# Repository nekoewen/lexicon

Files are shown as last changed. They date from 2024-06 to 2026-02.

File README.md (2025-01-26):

# Lexicon 65% Writing Keyboard

The Lexicon (or if you prefer the Lexicon 69 or the Cluney №3) is a 65% keyboard designed for writing prose, available from [WeirdLittleKeebs](https://www.weirdlittlekeebs.com/). With an extensive collection of shortcuts for words, formatting commands, and extended punctuation, this keyboard changes the experience of writing while maintaining a standard QWERTY layout. Check out the User's Guide to see how its unique features work.

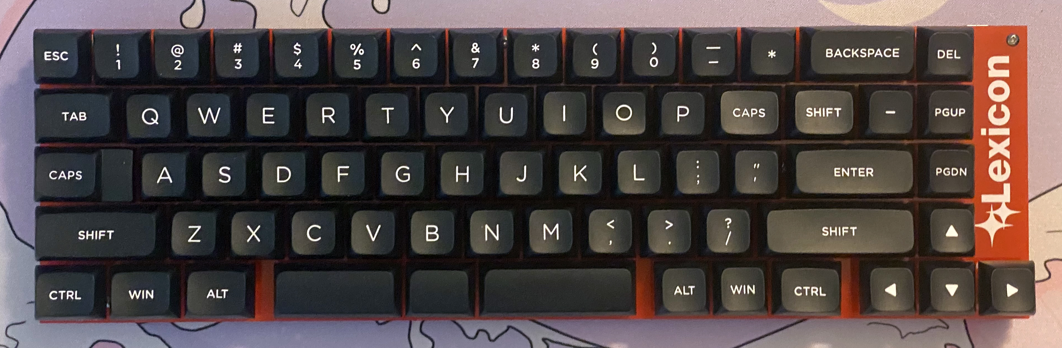
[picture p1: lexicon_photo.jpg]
A photo of a completed Lexicon keyboard


## [Build Guide](https://github.com/nekoewen/lexicon/blob/main/Lexicon%20Build%20Guide.pdf)
If you purchased a set of Lexicon PCB and plates, this guide will walk you through the assembly process.

## [User's Guide](https://github.com/nekoewen/lexicon/blob/main/Lexicon%20User's%20Guide.pdf)
Once you have a Lexicon ready to use, this guide explains all of its features in detail.



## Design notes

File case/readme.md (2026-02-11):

#Lexicon Case

This is a 3D-printable case designed by my good friend [Yenway](https://bsky.app/profile/did:plc:wb7yazpx56bxjeegsce3ni7f). It's made to be printed in two halves that can friction fit together with a pair of printed bars. Those and attaching the PCB make it feel fairly solid. It replaces the keyboard's bottom plate, and has divots for attaching eight adhesive rubber feet.

With PLA I've been able to print these without needing any supports, but it may become necessary for PETG. I recommend using variable layer height to reduce layer lines on the top.

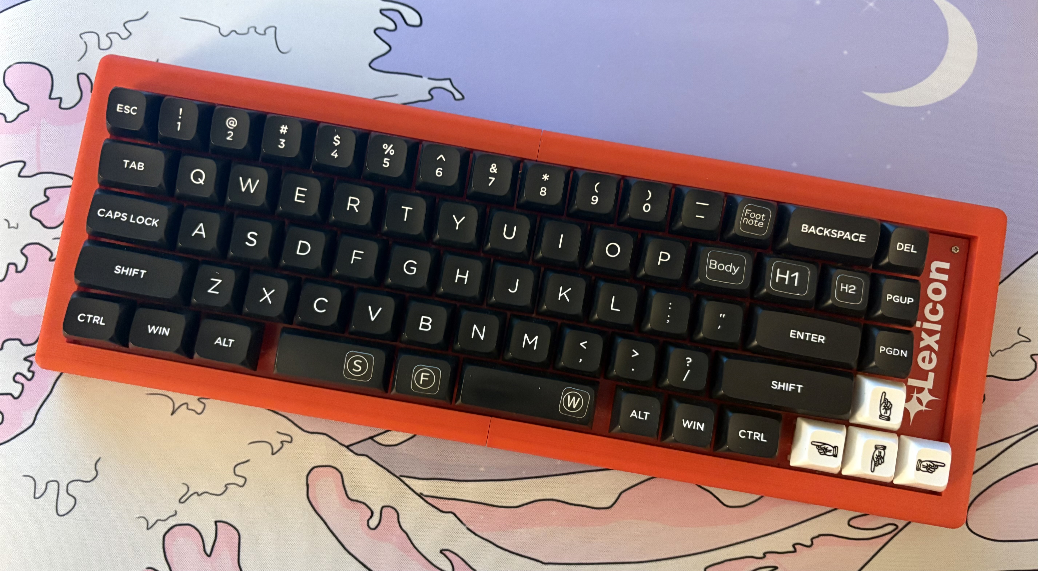
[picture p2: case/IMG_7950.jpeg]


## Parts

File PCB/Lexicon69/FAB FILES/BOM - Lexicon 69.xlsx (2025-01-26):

Designator | Comment | Footprint | LCSC Part #
C80, C81 | 22pF | 402 | C1563
C82 | 47uF | 3216 | C131173
C83, C84, C97 | 10uF | 805 | C15850
C85, C86 | 1uF | 402 | C52923
C87, C88, C90, C91, C92, C93, C94, C95, C96 | 0.1uF | 402 | C1525
C89 | 100nF | 402 | C1525
D1, D2, D3, D4, D5, D6, D7, D10, D11, D12, D14, D15, D16, D17, D18, D19, D20, D21, D22, D23, D24, D25, D26, D27, D28, D29, D30, D31, D32, D33, D34, D35, D36, D37, D38, D39, D40, D41, D42, D43, D45, D46, D47, D48, D49, D50, D51, D52, D53, D54, D55, D56, D57, D58, D60, D61, D62, D63, D64, D65, D66, D70, D72, D73, D74, D77, D132, D133, D134 | D | SOD-123 | C81598
F1 | 1A | 805 | C883105
J2 | USB C | SMD | C165948
R1, R2 | 5.1k | 402
R10, R11 | 22R | 402
R12, R13 | 1k | 402
R14 | 100k | 402
SW65 | RESET | Button_Switch_SMD:SW_SPST_SKQG_WithStem | C318884
U2 | USBLC6-2SC6 | SOT-23-6 | C7519
U4 | AMS1117-3.3 | SOT-223-3 | C6186
U5 | RP2040 | LQFN-56(7x7) | C2040
U6 | W25Q128JVS | SOIC-8-208mil | C97521
Y2 | 12MHz | SMD3225-4P | C9002

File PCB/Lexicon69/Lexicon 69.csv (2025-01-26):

Ref | Qnty | Value | Footprint | Vendor | DNP
C80, C81 | 2 | 22pF | 402 | 402
C82 | 1 | 47uF | 3216 | C131173
C83, C84, C97 | 3 | 10uF | 805 | C15850
C85, C86 | 2 | 1uF | 402 | C52923
C87, C88, C90, C91, C92, C93, C94, C95, C96 | 9 | 0.1uF | 402
C89 | 1 | 100nF | 402 | C1525
D1, D2, D3, D4, D5, D6, D7, D10, D11, D12, D14, D15, D16, D17, D18, D19, D20, D21, D22, D23, D24, D25, D26, D27, D28, D29, D30, D31, D32, D33, D34, D35, D36, D37, D38, D39, D40, D41, D42, D43, D45, D46, D47, D48, D49, D50, D51, D52, D53, D54, D55, D56, D57, D58, D60, D61, D62, D63, D64, D65, D66, D70, D72, D73, D74, D77, D132, D133, D134 | 69 | D | SOD-123 | C81598
F1 | 1 | 1A | 805 | C883105
J2 | 1 | USB C | SMD | C165948
R1, R2 | 2 | 5.1k | 402
R7 | 1 | DNP | 402
R10, R11 | 2 | 22R | 402
R12, R13 | 2 | 1k | 402
R14 | 1 | 100k | 402
SW65 | 1 | RESET | Button_Switch_SMD:SW_SPST_SKQG_WithStem | C318884
U2 | 1 | USBLC6-2SC6 | SOT-23-6 | C7519
U4 | 1 | AMS1117-3.3 | SOT-223-3 | C6186
U5 | 1 | RP2040 | LQFN-56(7x7) | C2040
U6 | 1 | W25Q128JVS | SOIC-8-208mil | C97521
Y2 | 1 | 12MHz | SMD3225-4P | C9002

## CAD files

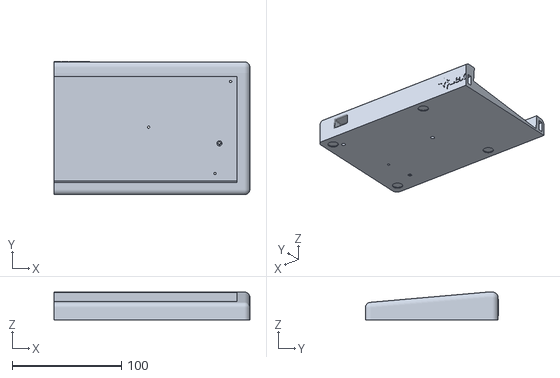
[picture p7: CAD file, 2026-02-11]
case/case_right.stl
179.5 x 122.0 x 25.5

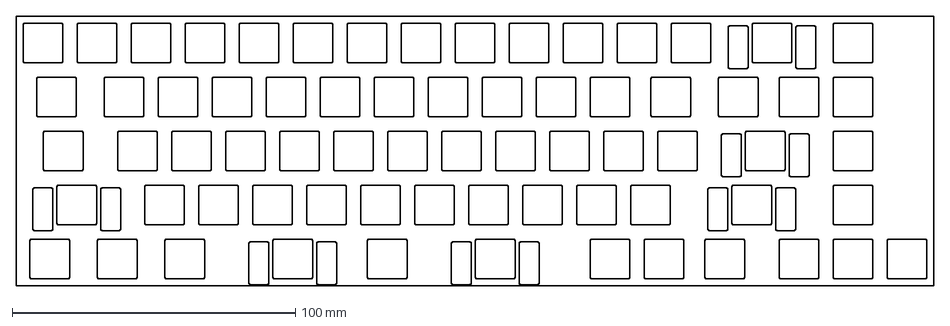
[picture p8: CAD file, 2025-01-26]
PCB/Lexicon69/`DATA/plate.dxf
323.9 x 95.2 mm

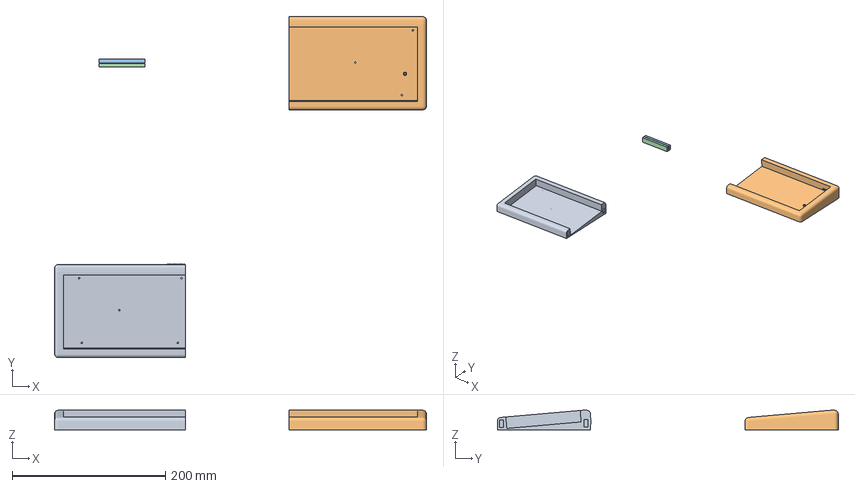
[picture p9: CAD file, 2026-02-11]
case/Lexiboard 2piece v7.3mf
484.8 x 445.0 x 25.5 mm
Body Left
Body Right

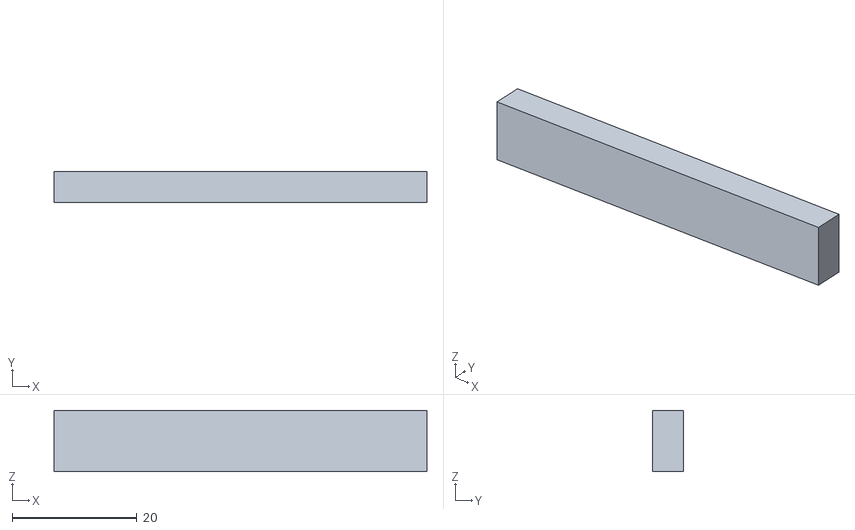
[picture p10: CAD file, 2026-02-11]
case/bar.stl
59.9 x 4.90 x 9.80

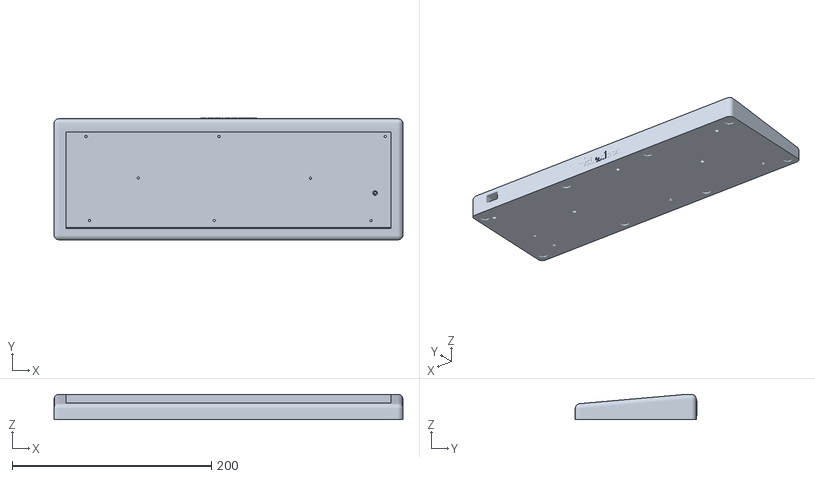
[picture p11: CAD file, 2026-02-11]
case/Lexiboard 1piece.stl
350.1 x 122.0 x 25.5

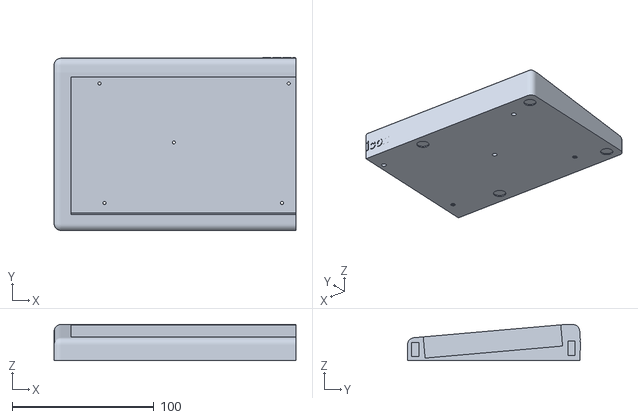
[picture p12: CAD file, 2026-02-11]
case/case_left.stl
170.6 x 122.0 x 25.5

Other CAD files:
case/Lexiboard 1piece v2.3mf

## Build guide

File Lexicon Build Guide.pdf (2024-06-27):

# Lexicon Build Guide

©2024 by Ewen Cluney
Although it has some complex firmware features, the Lexicon’s hardware is standard for hobbyist mechanical keyboards, and not difficult to assemble. This guide will walk you through the necessary steps. Please take appropriate safety precautions when soldering and working on electronics.
Most standard MX keycap sets will work with the Lexicon, but you will need 1.25u, 2.25u, and 2.75u keycaps for the split spacebar. Many keycap sets include these, but they can be purchased separately as well.

### Bill of Materials

Qty. | Item
1 set | Lexicon 69 PCB and plates
69 | MX-style switches
69 | MX-style keycaps
4+ | Adhesive feet
16 | M2 screws (4mm long)
8 | M2 standoffs (10mm long)
1 | USB-C cable

### Tools and Supplies

- Soldering iron
- Lead-free solder
- Precision screwdriver
- Metal tweezers

## Instructions

### Step 1: Flash Firmware

Plug the keyboard into your device with a USB-C cable. If it doesn’t show up as a drive (called RPI-RP2), hold the reset button while plugging it in. The reset button is on the underside of the PCB, a bit below the USB-C connector.
Drop the .uf2 file you want to use into the drive. The keyboard should reset and begin running the firmware.

### Step 2: Initial Test

Use metal tweezers to test each switch position to ensure that it produces a keystroke. We recommend using a keyboard tester (such as at keyboardtester.com) so you can easily see if each key is responding.

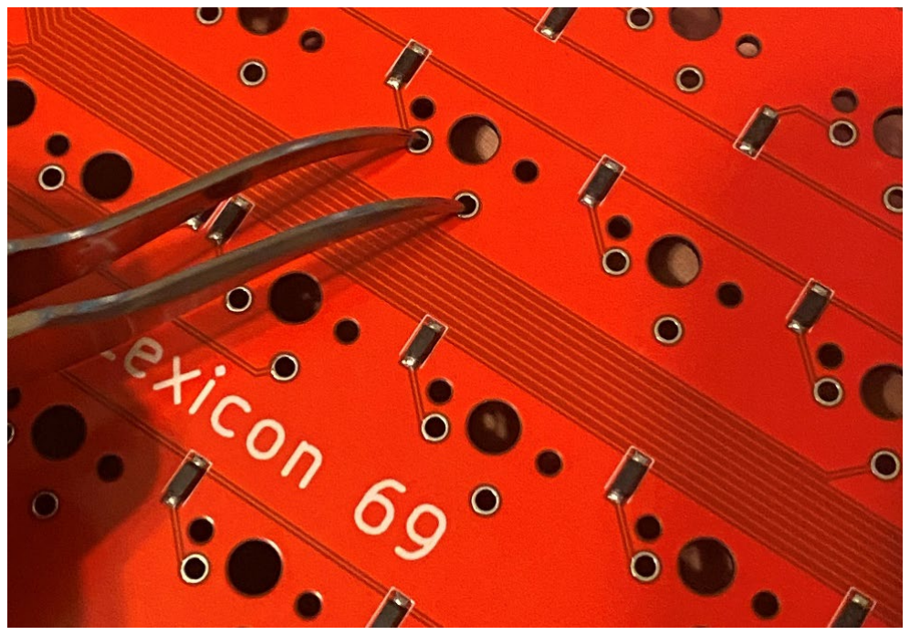
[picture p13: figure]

### Step 3: Stabilizers

Assemble the stabilizers and attach them to the PCB. The side with hooks goes into the larger holes, while the side with either a snap-in piece or threading for a screw goes into the smaller holes. In the case of screw-in stabilizers, use a screwdriver to insert and tighten the screws from the bottom of the PCB.

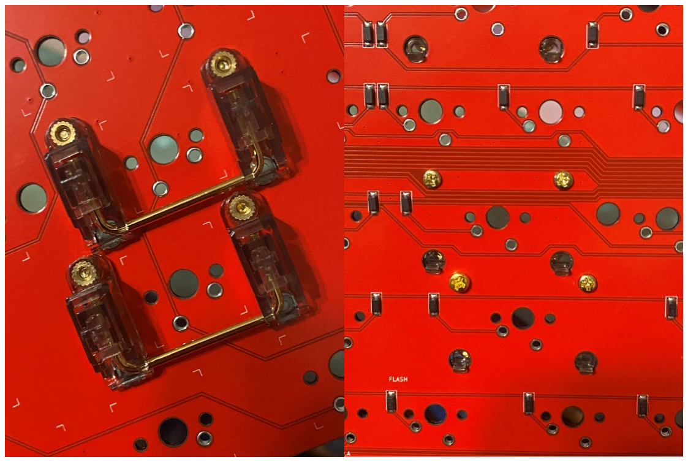
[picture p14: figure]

### Step 4: Top Plate Hardware

Attach screws and standoffs to the top plate. The screws should go into the side with the Lexicon logo, with the standoffs on the opposite side.

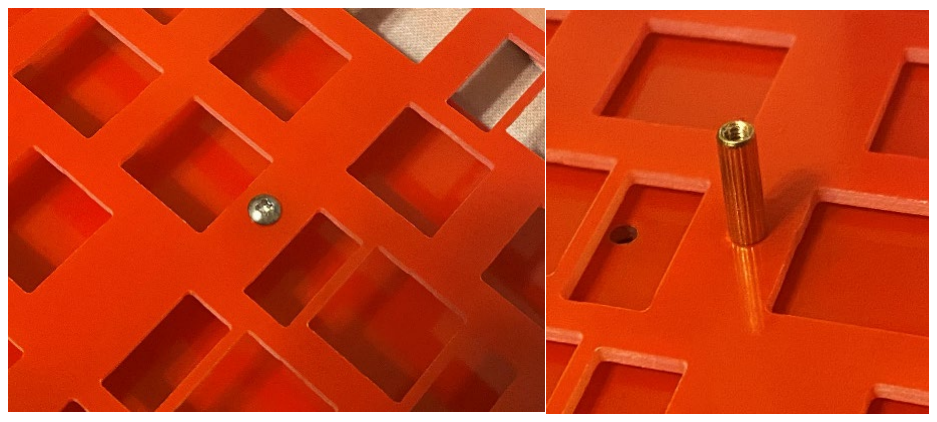
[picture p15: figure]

### Step 5: Place and Solder Switches

Seat some switches in the top plate (the pins should be toward the bottom of the keyboard), then solder them in place on the PCB. From there, continue inserting and soldering switches until they’re all done.

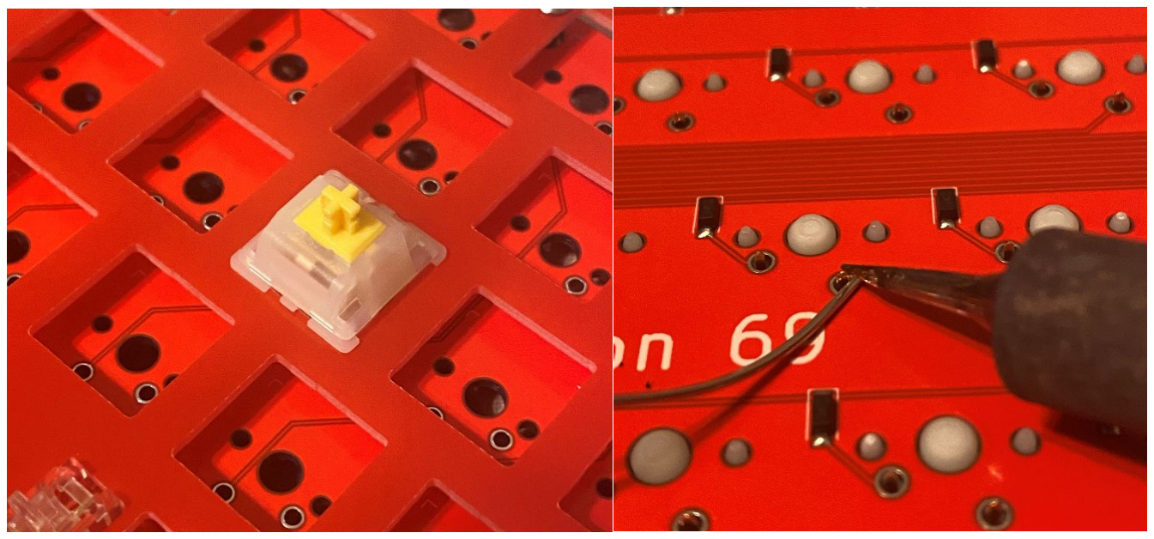
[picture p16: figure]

The Caps Lock key has two sets of contacts placed close together. The left one is for using a stepped keycap, while the right is for a non-stepped one. Decide which you’re going to use before soldering that switch. Not all keycap sets include both types of Caps Lock keycaps.
Plug the keyboard in and test the switches. Make sure you haven’t missed soldering any or bent any pins.

### Step 6: Place Keycaps

Place the keycaps on the switches. For the keycaps that go onto stabilizers, make sure they properly move up and down. The included sticker sheet has labels for some of the keys to use if you wish.

### Step 7: Bottom Hardware

Use screws to attach the bottom plate. The side with artwork goes on the bottom of the keyboard, so that the hole for the reset switch sits over the button.

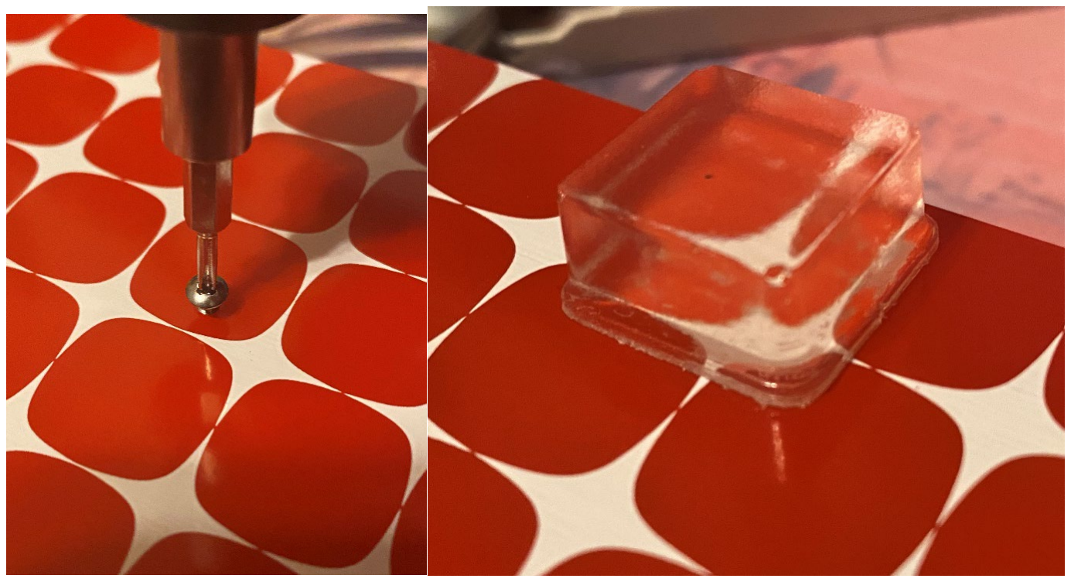
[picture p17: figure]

Affix rubber feet to the bottom plate. If you want the keyboard to have a tilt, put taller feet on the rear portion of the board’s bottom.
You’re done! Time to get to writing!

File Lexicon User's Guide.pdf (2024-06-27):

# Lexicon User’s Guide

©2024 by Ewen Cluney (weirdlittlekeebs.com)
Version 1.0
☞ The Lexicon is a mechanical keyboard made for writing. It can’t make you a better writer, but it does put essential punctuation and shortcuts in easy reach. It even has shortcuts that type out whole words for you!

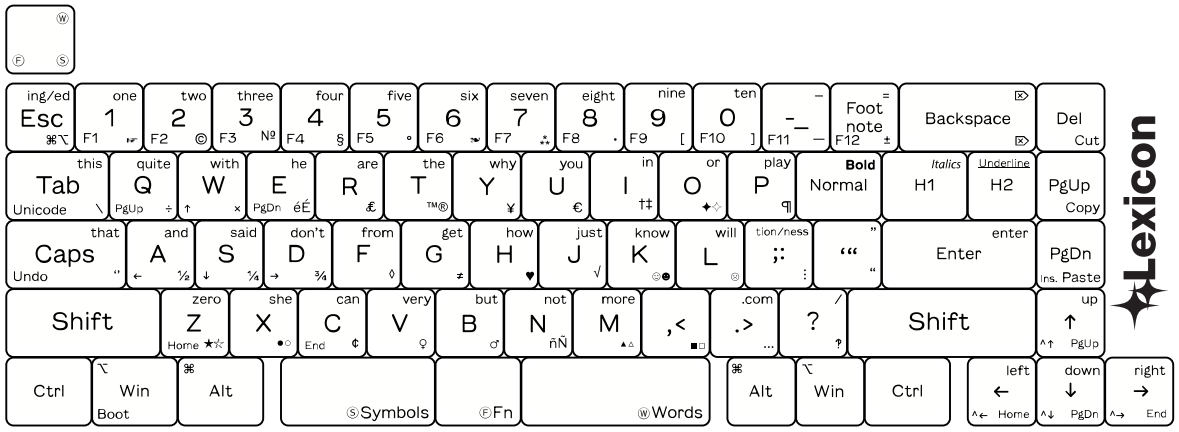
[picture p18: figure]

The Lexicon uses the QMK open-source firmware package (qmk.fm). You don’t have to learn how to customize the QMK keymap to use the keyboard, but that’s a powerful way to change the keyboard’s functionality to your liking. It also uses the power of the Raspberry Pi RP2040 controller chip, allowing for complex firmware with many features. Even with everything the Lexicon already uses, there’s plenty of room for anything you might want to add.

## Compatibility

The Lexicon will work with most devices that take input from standard USB HID keyboards, including Windows, macOS, and Linux computers, as well as Chromebooks and Android and iOS devices. The Symbols layer (see below) relies on Unicode input and may not work on all platforms.

## The Space Bars

The heart of the Lexicon’s unique functionality is accessible via its three space bars. Each one produces a space when pressed briefly and activates a different set of key functions when held down.

- The leftmost is the Symbols key. This makes the keys produce various Unicode symbols. In this manual the Ⓢ symbol represents the Symbols key.
- The small middle space is for the Function layer, which gives you access to function keys and other special commands. In this manual the Ⓕ symbol represents the Function space.
- The largest, rightmost space is the Words key. The Words layer has shortcuts that produce whole words. In this manual the Ⓦ symbol represents the Words key.
In this manual the ⇧ symbol represents the Shift key; both the Symbols and Words layers have capabilities that use Shift. Also, although the Words and Symbols layers are mostly for the things in their names, there are a few exceptions to make certain functions easier to access.

### Meet Lexi

If you look at the Lexicon’s bottom plate, you’ll see artwork of Lexi, the keyboard’s mascot character, by retrotv5000 (retrotvart.com). Lexi is a vivacious young typist from an idealized version of the 1960s, sporting a flip hairstyle and mod dress. Check your packaging for a free Lexi sticker!

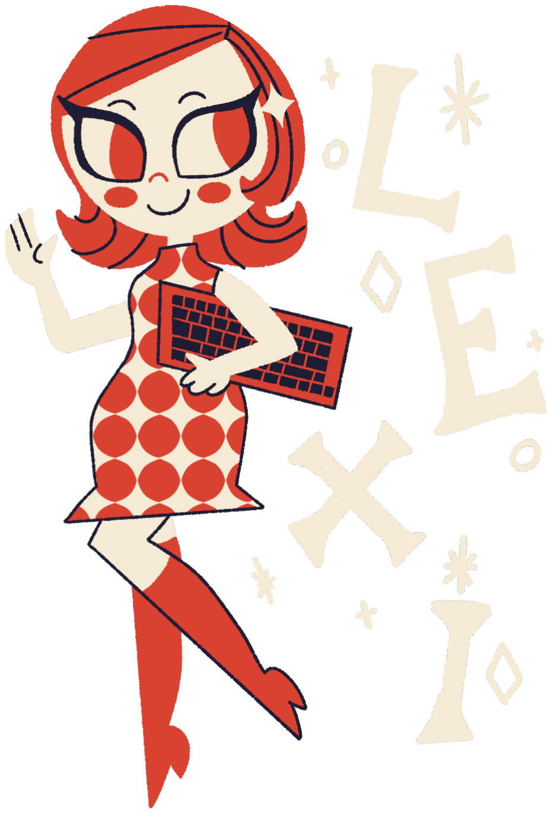
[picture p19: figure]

## Shortcut Keys

The Lexicon has several keys assigned to various hotkeys for common functions in various word processors. In the default firmware they’re based on the hotkeys for Microsoft Word on Windows; there are alternate keymaps and compiled firmware profiles for several other combinations of OS and word processor. Keystrokes marked with an asterisk are those that the user has to configure in the word processor themselves, explained in greater detail below.
Command | Windows | macOS
Undo | Ctrl-Z | ⌘Z
Bold | Ctrl-B | ⌘B
Italics | Ctrl-I | ⌘I
Cut | Ctrl-X | ⌘X
Copy | Ctrl-C | ⌘C
Paste | Ctrl-V | ⌘V

### Microsoft Word

Command | Word (Windows) | Word (macOS)
“Normal” Style | Ctrl-Shift-N | ⌘⇧N
“Heading 1” Style | Ctrl-Alt-1 | ⌘⌥1
“Heading 2” Style | Ctrl-Alt-2 | ⌘⌥2
Footnote | Ctrl-Alt-F | ⌘⌥F
The Android and iOS versions of Word use the same keyboard shortcuts as the Windows and macOS versions respectively.

### Google Docs

Command | Google Docs | gDocs (macOS)
“Normal” Style | Ctrl-Alt-0 (zero) | ⌘⌥0 (zero)
“Heading 1” Style | Ctrl-Alt-1 | ⌘⌥1
“Heading 2” Style | Ctrl-Alt-2 | ⌘⌥2
Footnote | Ctrl-Alt-F | ⌘⌥F
The Android and ChromeOS versions of Google Docs use the same shortcuts as on Windows, while the iOS version uses the same shortcuts as on macOS.

### LibreOffice

Command | LibreOffice Writer | LibreOffice (macOS)
“Normal” Style | Ctrl-0 | ⌘0
“Heading 1” Style | Ctrl-1 | ⌘1
“Heading 2” Style | Ctrl-2 | ⌘2
Footnote | *Ctrl-Shift-F | *⌘⌥F
LibreOffice does not have a shortcut for footnotes by default, but you can define one yourself. To create a new shortcut, open Tools > Customization, then click the Keyboard tab. Select the “Insert” Category and the “Footnote” function, then pick a key combination under Shortcut Keys, and finally click the Assign button. The pre-made Lexicon keymaps use the Word shortcuts (Ctrl-Shift-F or ⌘⌥F on macOS).

### Pages

Command | Pages (macOS)
“Normal” Style | *F8
“Heading 1” Style | *F1
“Heading 2” Style | *F2
Footnote | *⌘⌥F
Pages does not have keyboard shortcuts for styles or footnotes by default.
To assign a shortcut to a style, open the list of styles, click the > to the right of the style’s name, and select a Function key under Shortcut.
To assign a shortcut to creating a footnote, open the Keyboard section of System Preferences, click “Keyboard Shortcuts…”, click “App Shortcuts,” click +, select Pages, enter “Footnote” as the Menu title, and finally enter your desired keystroke under “Keyboard shortcut.”

## Symbols Layer

The Symbols layer provides quick access to numerous characters and typographical marks. Some are very common symbols used in writing, but most are a whimsical selection of typographical oddities.
Most of these use Unicode output, so the keyboard and your OS have to be configured correctly for them to work. If these key combinations don’t work or produce a seemingly random series of numbers or characters, it isn’t set up properly.

### Changing Modes

To change the keyboard’s Unicode output mode, press ⒻTab to cycle between WinCompose, macOS, and Linux modes. The keyboard will remember which mode is selected even when it’s unplugged or the device it’s connected to is shut down.

### Windows

Using Unicode output in Windows require installing a free app called
WinCompose, available at wincompose.info. Once it’s installed and running, it should recognize Unicode input from the Lexicon.

### macOS

In macOS you will need to enable Unicode Hex Input. Open System Settings > Keyboard, go to Text Input, click Edit…, click the +, scroll to the bottom and select Others and Unicode Hex Input. You can then switch to Unicode Hex Input. It’s easier to do this if you click “Show Input menu in menu bar,” which will then let you click to select which input mode you want.
Since this mode uses the Option key, you will not have access to the usual macOS character shortcuts that use it while Unicode Hex Input is active. Also, note that changing which key produces Option can cause Unicode input from the keyboard to stop working.

### Linux

For Linux, the firmware is using the Ctrl-Shift-U shortcut. Most Linux distributions include this shortcut, but not all. Since ChromeOS is based on Linux, the Linux mode should work on Chromebooks.

Ⓢ

1 manicule

☞
Ⓢ

H

heart

♥

Ⓢ

2 copyright

©
Ⓢ

I dagger

†

Ⓢ

3 numero

№

⇧
Ⓢ

I double dagger

‡

Ⓢ

4 section

§
Ⓢ

J root

√

Ⓢ

5 degree

°
Ⓢ

K

smile 1

☺

Ⓢ

6 fleuron

❧
⇧
Ⓢ

K

smile 2

☻

Ⓢ

7 asterism
⁂
Ⓢ

L frown

☹

Ⓢ

8 Bullet

•
Ⓢ

M triangle 1

▲

Ⓢ

9

left

bracket

[

⇧
Ⓢ

M triangle 2

△

Ⓢ

0

right

bracket

]
Ⓢ

N enye

ñ
Ⓦ
- en dash

–

⇧
Ⓢ

N capital enye

Ñ
Ⓦ

" close quote

”
Ⓢ

O

4

pointed

star 1

✦

Ⓢ

" open quote

“

⇧
Ⓢ

O

4

pointed

star 2

✧

Ⓢ

,

box 1

■
Ⓢ

P pilcrow

¶
⇧
Ⓢ

,

box 2

□
Ⓢ

Q bolus

÷
Ⓢ

. ellipsis

…
Ⓢ

R pound

£
Ⓢ

: tricolon

⁝
Ⓢ

S quarter

¼
Ⓢ

? interrobang

‽
Ⓢ

T

trademark

™

Ⓢ

- em dash

—

⇧
Ⓢ

T registered

®
Ⓢ

+

plus or

minus

±
Ⓢ

U euro

€
Ⓢ

A half

½
Ⓢ

V

female

♀

Ⓢ

B Male

♂
Ⓢ

W multiplication

×
Ⓢ

C cent

¢
Ⓢ

X circle 1

●

Ⓢ

D three quarters

¾

⇧
Ⓢ

X circle 2

○

Ⓢ

E accent E

é
Ⓢ

Y yen

¥
⇧
Ⓢ

E capital accent

E

É
Ⓢ

Z

star 1

★

Ⓢ

F lozenge

◊
⇧
Ⓢ

Z

star 2

☆

Ⓢ

G

not

equal

≠

ⓈTab | backslash | \ | Ⓢ↑ | PgUp
Ⓢ⇧Tab | pipe/vertical bar | | | Ⓢ↓ | PgDn
Ⓢ⇧9 | left curly bracket | { | Ⓢ← | Home
Ⓢ⇧0 | right curly bracket | } | Ⓢ→ | End
ⓌFootnote | equals sign | = | ⓈBackspace | Delete
Ⓦ⇧Footnote | plus sign | + | ⓈDel | Cut
ⓈFootnote | plus or minus | ± | ⓈPgUp | Copy
ⓈEsc | Command | ⌘ | ⓈPgDn | Paste
Ⓢ⇧Esc | Option | ⌥
ⓈCaps | open single quote | ‘ | Win-Esc | `
⇧ⓈCaps | close single quote | ’ | Shift-Esc | ~

### Grave Escape

If you’re looking for the key with the tilde ~ and grave accent `, the Lexicon uses a QMK feature called the “grave escape.” When used normally, Escape is an ordinary Escape key, but Shift-Escape gives you a tilde and Windows-Escape (or ⌘Esc in macOS) gives you a grave accent.

## Words Layer

Holding down the Words space bar activates the Words Layer. On that layer, each letter key produces a specific word, as do certain other keys. Word shortcuts are typed without spaces before or after, so you’ll need to add spaces yourself.

### Capitalization

Holding Shift while using a word shortcut will give you that word with the first letter capitalized. For example, holding Shift and pressing ⓌP would give you “Play” instead of “play.” There are also a handful of instances where using Shift will produce something entirely different.
This will only happen for the first word shortcut you use in a given instance of holding down the Shift key, so you will have to release Shift and press it again to use the capitalization feature on multiple consecutive words.
ⓌA | and | ⓌP | play | Ⓦ1 | one | ⓌCaps | tion
ⓌB | but | ⓌQ | quite | Ⓦ2 | two | ⇧ⓌCaps | ness
ⓌC | can | ⓌR | are | Ⓦ3 | three | Ⓦ. | .com
ⓌD | don’t | ⓌS | said | Ⓦ4 | four | ⇧Ⓦ. | .net
ⓌE | he | ⓌT | the | Ⓦ5 | five | Ⓦ? | /
ⓌF | from | ⓌU | you | Ⓦ6 | six | Ⓦ⌫ | Delete
ⓌG | get | ⓌV | very | Ⓦ7 | seven
ⓌH | how | ⓌW | with | Ⓦ8 | eight
ⓌI | in | ⓌX | she | Ⓦ9 | nine
ⓌJ | just | ⓌY | why | Ⓦ0 | ten
ⓌK | know | ⓌZ | zero | Ⓦ⏎ enter
ⓌL | will | ⓌTab | this | Ⓦ↑ | up
ⓌM | more | ⓌCaps | that | Ⓦ↓ | down
ⓌN | not | ⓌEsc | ing | Ⓦ← | left
ⓌO | or | ⇧ⓌEsc | ed | Ⓦ→ | right

## Word Combos

A “combo” is a keyboard feature where pressing multiple keys simultaneously produces different output. The Lexicon has a set of two-key combos to add more shortcuts to type common words.

### Capitalization

You can also capitalize words from word combos, but this works differently from the Words layer. To capitalize a word combo, tap the Shift key and the two letter keys at the same time. Holding Shift and pressing SG will produce “SOMETHING,” but pressing S, G, and Shift at the same time produces “Something.”

### Timing

The firmware has a value called COMBO_TERM (in the keymap’s config.h file), which determines the length of the time window for entering a combo. Depending on your typing habits, you may find it easier to change this value, to ensure that you aren’t accidentally entering combos when you don’t mean to or not getting them when you want to. If they don’t work for you, you can disable them entirely.

### Creating New Combos

The firmware stores the definitions for combos in a “combos.def” file; you can modify or add to these by following the same format. For example:
SHIFT_SUBS(SG_SOMETHING, | "something", | "Something", | KC_S, KC_G)
“SG_SOMETHING” is an ID for the combo, which needs to be unique among the labels used in the keyboard firmware. The word to be typed appears in quotes, and has both lower case and capitalized versions, the latter being what shows up when you hold Shift when using the combo. Lastly there are the keycodes for the keys the user will press simultaneously to activate the combo. You can find a list of keycodes available in QMK here: https://github.com/qmk/qmk_firmware/blob/master/docs/keycodes.md
Note that although the firmware will compile, combos that use keys assigned to layer-tap or mod-tap functions will not work. On the Lexicon that means you can’t use Space in any combos unless you change one of the space bars to only be used for KC_SPC.

able | BL | have | HV | than | TA
about | AB | idea | YD | their | TR
after | AF | important | PR | them | TM
already | LR | into | NO | then | TN
also | AL | keep | KP | there | TH
another | NR | know | KN | these | TZ
any | NY | like | LE | they | TY
anything | AG | little | LI | they're | T'
aren't | AR | look | LK | thing | TG
back | BK | make | MK | think | TK
because | BC | more | ME | though | ZO
been | BN | need | ND | time | TI
before | BF | new | NU | until | NL
being | BG | nothing | NG | use | UZ
come | CM | okay | OK | very | VY
company | CP | only | OY | want | WT
could | CO | other | OR | was | WA
didn't | DI | out | OT | wasn't | WN
doesn't | DT | over | OV | way | WY
easy | EZ | people | PL | well | WL
enough | NF | please | PZ | were | WR
especially | SP | really | RY | what | WH
even | EN | remember | RM | when | WE
first | FI | should | SO | which | WI
for | FR | shouldn't | SN | work | WK
give | GI | some | SM | would | WO
good | GD | somebody | SB | yes | YS
guy | G
| Y | something | SG | your | YO
had | HD | still | ST | you're | UR
hahaha | HA | stuff | SF | you've | UF
has | HZ | take | TE

## Function Layer

The Function Layer, accessed with the small middle space, includes additional keystrokes not covered elsewhere in the Lexicon’s layout. This includes the function keys, as well as alternate navigation keys so you can access those with just your left hand.
Ⓕ1-0 | F1-F10 | ⒻW | ↑ | macOS Navigation Keys
Ⓕ- (dash) | F11 | ⒻA | ← | Ⓕ↑ | ⌘↑
ⒻFootnote | F12 | ⒻS | ↓ | Ⓕ↓ | ⌘↓
Ⓕ↑ | Ctrl-↑ | ⒻD | → | Ⓕ← | ⌥←
Ⓕ↓ | Ctrl-↓ | ⒻQ | Page Up | Ⓕ→ | ⌥→
Ⓕ← | Ctrl-← | ⒻE | Page Down
Ⓕ→ | Ctrl-→ | ⒻZ | Home
ⒻBackspace | Delete | ⒻC | End
ⒻCaps | Undo | ⒻPgDn | Insert

### Bootloader

Pressing Ⓕ and the left Windows key (or the left Option key on macOS layouts) will put the keyboard into bootloader mode for flashing new firmware. If you do this unintentionally, the keyboard will stop responding to keystrokes, but you can just unplug it and plug it back in again.

### Unicode

As noted in the section on the Symbols layer, pressing ⒻTab cycles through WinCompose, macOS, and Linux Unicode input modes.

## Flashing the Firmware

Because the Lexicon runs an RP2040 chip, the compiled firmware takes the form of .uf2 files. If you have the .uf2 file available, it’s fairly easy to re-flash your keyboard with that profile.
There are two methods for putting the keyboard into bootloader mode:
- The PCB has a reset button on the bottom, below the USB connector. The bottom plate has a hole that lets you press the button with a screwdriver or similar. Hold the button down while plugging it in.
- Hold the Function spacebar and press the left Windows key (or the left Option key on macOS).
Either one should make the keyboard’s controller appear as a disk drive called RPI-RP2. Drag the .uf2 file into this drive, and the keyboard will reset and begin running the new firmware.
There are several pre-compiled .uf2 files available, to cover different word processors, operating systems, and uses:
default | Word for Windows
macword | Word for macOS
libreoffice | LibreOffice Writer on Windows or Linux
libremac | LibreOffice Writer on macOS
gdocs | Google Docs on Windows, Linux, or ChromeOS
gdocsmac | Google Docs on macOS
pages | Pages on macOS
basic | A keymap that removes the Lexicon features, making it act like a standard 65% keyboard.
via | A version of the Basic keymap with support for the VIA customization app, available at caniusevia.com. See below for instructions on how to use it with the Lexicon.

Note that the macOS versions transpose the Alt and Windows keys to match how the Option and Command keys are laid out on Mac keyboards.

### You Can Use VIA

To use VIA on that version of the firmware, you’ll need to go to usevia.app in a web browser with WebHID support. Most current browsers have that, though Firefox is a notable exception.
1. Click the gear icon to access settings.
2. Toggle “Show Design tab” to ON.
3. Click the paintbrush icon for the Design tab.
4. Click the “Load” button and then select the lexicon69.json file.
You should now be able to edit the keymap in VIA’s Configure tab.

## Modifying the Firmware

To modify and compile firmware on your own, you’ll need to set up a command line environment for QMK. In Windows that means installing QMK MSYS, while for macOS or Linux you’ll instead add QMK to your system’s terminal. Visit qmk.fm to learn more.
This manual notes some places where you may want to modify the firmware, but of course you can change it as much as you want. QMK’s directory has a keyboards folder, in which you can find the profiles for various keyboards. These are in simple C code, and you can make changes with a text editor. You’ll need to move the lexicon69 folder into your keyboards folder; you’ll then be able to compile Lexicon firmware from the command line.
The aliases.c file defines a series of keycodes for the formatting shortcuts, which the keymaps reference. You can quickly switch to shortcuts for different platforms and software by changing which sets of keycodes have comment markers /* */ in the file, without having to alter them in the keymap.
Once you have your modifications ready, open MSYS or your terminal, go to the QMK directory (typically “cd qmk_firmware”), and then “make:lexicon:default” (or replace “default” with the name of your keymap). That should compile the firmware, though of course there may be errors to contend with. Once it’s compiled you can flash it as explained above, though from there it’s best to test it to ensure that the compiled firmware functions how you want.

## Tips

- The word shortcuts are there if you want to use them, but it’s totally fine if you don’t, whether you miss the opportunity once in a while or decide to ignore them entirely. Using them can make you think more about the specific words you’re using; whether that’s helpful is for you to decide.
- If the app you’re using has automatic suggestions, they can further help you along. When grayed-out words appear ahead of the cursor, you can typically press Tab or right arrow to accept them, or just ignore them and keep typing.
- Caps Lock affects word shortcuts just like with normal typing.
- Capitalizing word combos is generally easier if you press Shift with a hand not busy with hitting the letter keys.
- You can use the word shortcuts to produce part of a word and add more. If you want to type “note,” you can press ⓌN for “not” and then type the
E. You can even combine shortcuts; for example, pressing SM followed by Ⓦ1 will give you “someone.”
- If you’re using multiple consecutive Words layer shortcuts, you can hold the Words spacebar down and use the Symbols and Function spacebars to add spaces between the words.
- While the functionality of word shortcuts is useful, it does create exciting new kinds of typos, which you’ll want to be aware of when proofreading text written with a Lexicon. Watch for missing and extraneous words and chunks of words, as well as incorrect words.
- The Shift key works on standard symbols even when you’re using them via a layer. For example, if you need curly brackets, that would be ⇧Ⓢ9 and ⇧ Ⓢ0. Virtually any keystroke available on a standard keyboard is on the Lexicon in some form.
- Since the space bars double as the means to access alternate layers, you can’t enter a bunch of spaces by holding them down, but since there are three of them, you can mash on all of them instead.
- You can use the Lexicon for things other than writing, though it may not be as good for some purposes. With a few exceptions like text adventure games (“ⓌG lamp”), keymaps with Lexicon’s special functions won’t be good for gaming. If you do want to use it for a typical computer game, we recommend flashing it with the Basic or VIA firmware.

### Trivia

- If you really enjoy getting words out with simple shortcuts, check out steno via the Open Steno Project at openstenoproject.org. The Lexicon’s word shortcuts give you kind of a light form of steno, and many of its combos are based on steno chords.
- If you know the Lexicon word shortcuts well enough, you can use them as a simple shorthand when writing. Try writing the letter(s) for a shortcut and underlining them. For example, “Why did he get something from there?” could be “Y did e g sg f th?” Save time and baffle your friends!
- The four solder points in a row on the PCB are an SWD (single wire debug) interface, a common feature used for debugging. If you end up using it for something let us know, because that sounds neat.
- The Lexicon is also known as the Lexicon 69 (because it has 69 keys), or the Cluney №3 (because it’s Ewen Cluney’s third keyboard design).
- The Lexicon takes some aesthetic inspiration from the Olivetti Valentine portable typewriter. For the full effect, use black or dark gray keycaps.
- The inspiration for word shortcuts came from the Sinclair ZX Spectrum’s BASIC programming shortcuts.

## Credits

Keyboard design and manual by Ewen Cluney
PCB design by Supul/circuitwork32
Additional design and firmware assistance by DeskDaily Word shift programming by Phoebe Zeitler
Lexi art by retrotv5000 (retrotvart.com)
Testing by C. Ellis, Steven Savage, Phoebe Zeitler
Special thanks to Marcin Wichary, Mirabai Knight, SethSempai, Vladimir Glushkov, Danny Nguyen, Clay Gardner

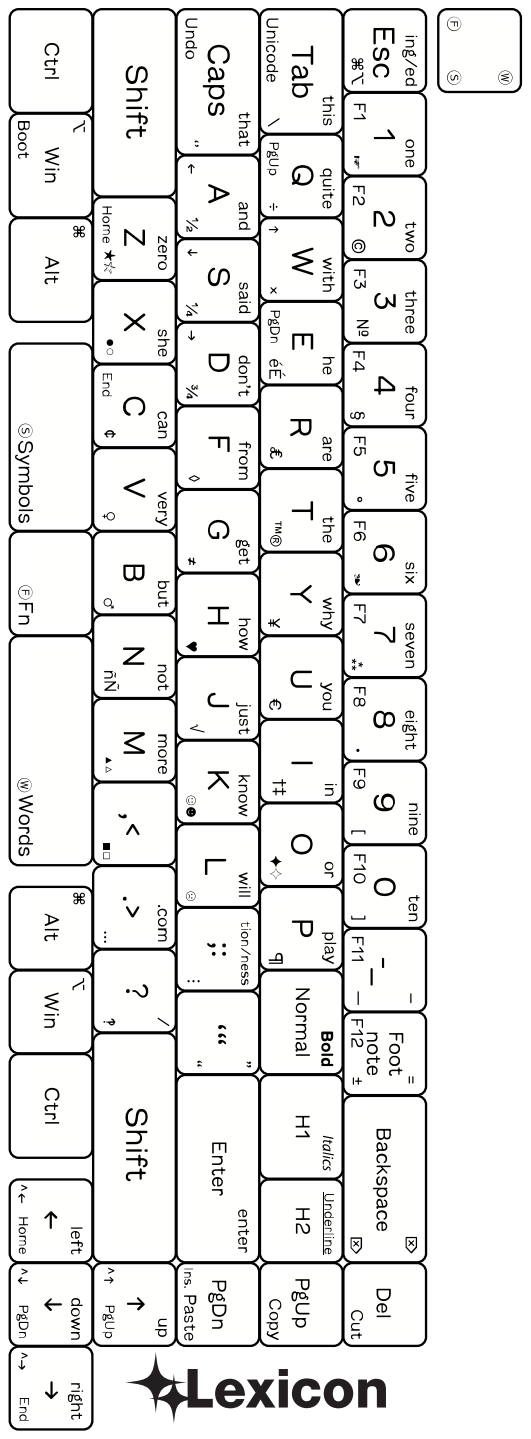
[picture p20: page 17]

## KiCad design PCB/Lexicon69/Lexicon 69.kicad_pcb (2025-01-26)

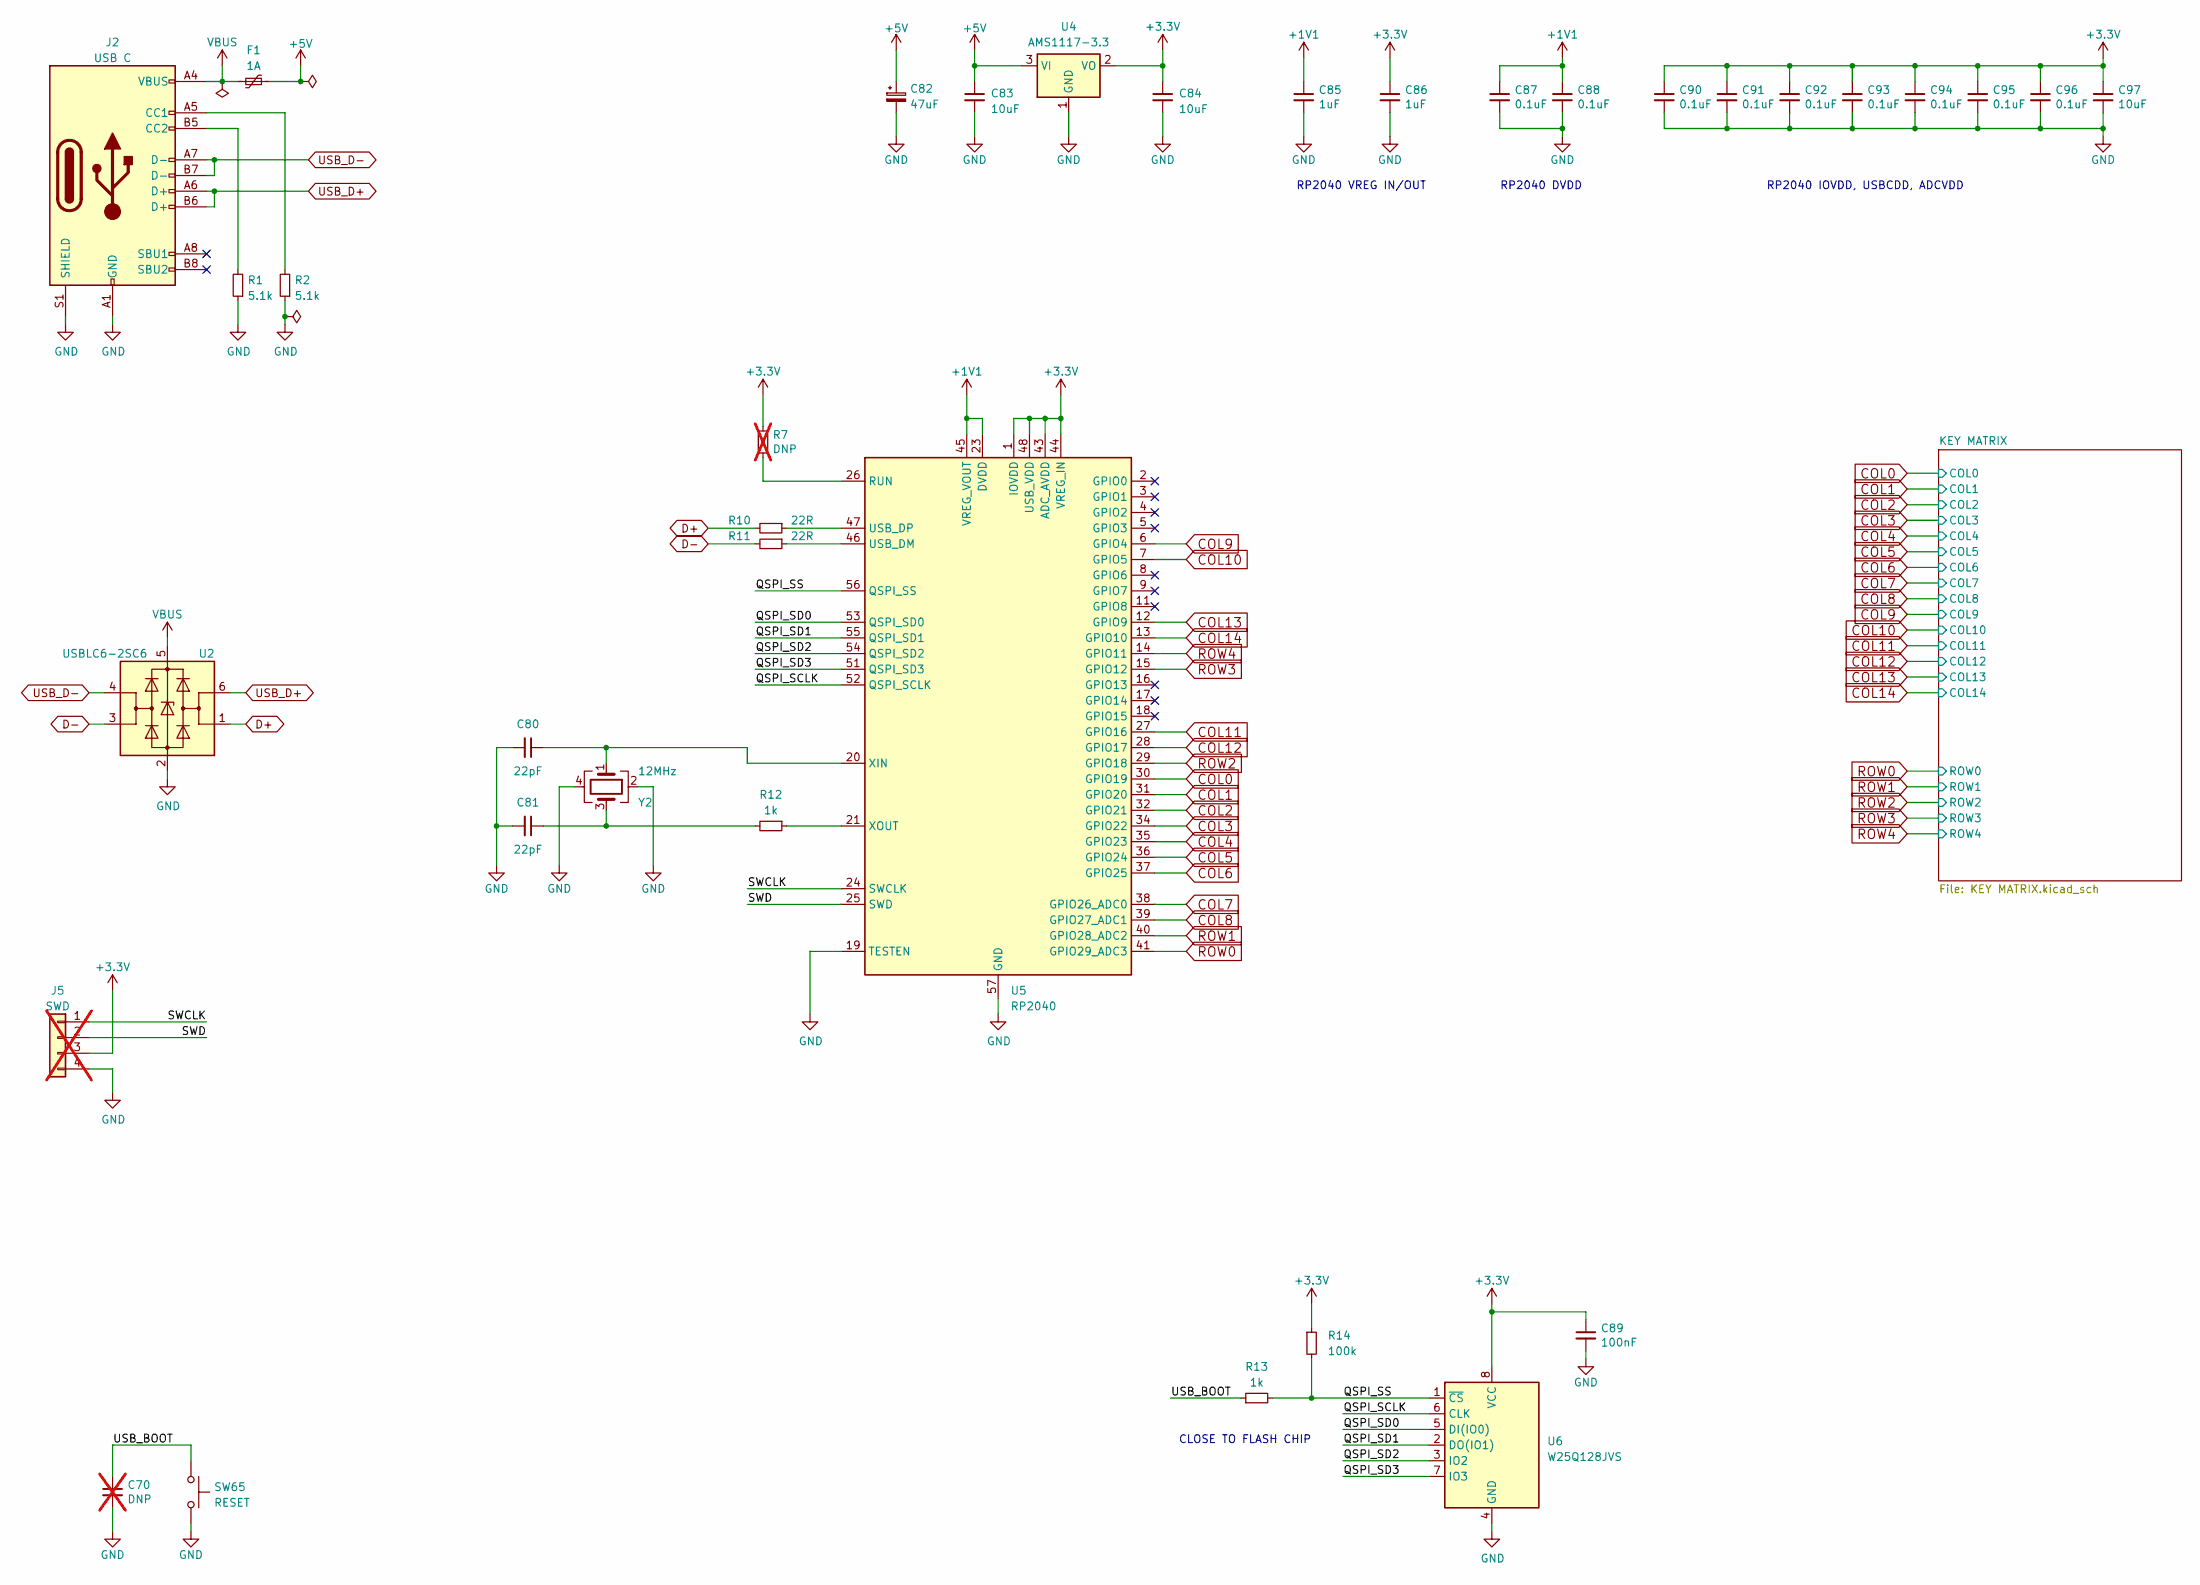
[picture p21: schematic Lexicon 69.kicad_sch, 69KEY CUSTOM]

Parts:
C70: DNP; C_0402_1005Metric; not fitted
C80, C81: 22pF; C_0402_1005Metric
C82: 47uF; CP_EIA-3216-10_Kemet-I
C83, C84, C97: 10uF; C_0805_2012Metric
C85, C86: 1uF; C_0402_1005Metric
C87, C88, C90, C91, C92, C93, C94, C95, C96: 0.1uF; C_0402_1005Metric
C89: 100nF; C_0402_1005Metric
F1: 1A; Fuse_0805_2012Metric
J2: USB C; USB_C_Receptacle_HRO_TYPE-C-31-M-12
J5: SWD; PinHeader_1x04_P2.54mm_Vertical; not fitted
R1, R2: 5.1k; R_0402_1005Metric
R7: DNP; R_0402_1005Metric; not fitted
R10, R11: 22R; R_0402_1005Metric
R12, R13: 1k; R_0402_1005Metric
R14: 100k; R_0402_1005Metric
SW65: RESET; SW_SPST_SKQG_WithStem
U2: USBLC6-2SC6; SOT-23-6
U4: AMS1117-3.3; SOT-223-3_TabPin2
U5: RP2040; QFN-56-1EP_7x7mm_P0.4mm_EP3.2x3.2mm
U6: W25Q128JVS; SOIC-8_5.23x5.23mm_P1.27mm
Y2: 12MHz; Crystal_SMD_SeikoEpson_FA238-4Pin_3.2x2.5mm

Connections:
+1V1: C85.1, C87.1, C88.1, U5.23 (DVDD), U5.45 (VREG_VOUT), U5.50 (DVDD)
+3.3V: C84.1, C86.1, C89.1, C90.1, C91.1, C92.1, C93.1, C94.1, C95.1, C96.1, C97.1, J5.3, R7.1, R14.1, U4.2 (VO), U5.1 (IOVDD), U5.10 (IOVDD), U5.22 (IOVDD), U5.33 (IOVDD), U5.42 (IOVDD), U5.43 (ADC_AVDD), U5.44 (VREG_IN), U5.48 (USB_VDD), U5.49 (IOVDD), U6.8 (VCC)
+5V: C82.1, C83.1, F1.1, U4.3 (VI)
/QSPI_SCLK: U5.52 (QSPI_SCLK), U6.6 (CLK)
/QSPI_SD0: U5.53 (QSPI_SD0), U6.5 (DI(IO0))
/QSPI_SD1: U5.55 (QSPI_SD1), U6.2 (DO(IO1))
/QSPI_SD2: U5.54 (QSPI_SD2), U6.3 (IO2)
/QSPI_SD3: U5.51 (QSPI_SD3), U6.7 (IO3)
/QSPI_SS: R13.2, R14.2, U5.56 (QSPI_SS), U6.1 (~CS)
/SWCLK: J5.1, U5.24 (SWCLK)
/SWD: J5.2, U5.25 (SWD)
/USB_BOOT: C70.1, R13.1, SW65.1
COL0: U5.30 (GPIO19); also elsewhere on the board
COL1: U5.31 (GPIO20); also elsewhere on the board
COL2: U5.32 (GPIO21); also elsewhere on the board
COL3: U5.34 (GPIO22); also elsewhere on the board
COL4: U5.35 (GPIO23); also elsewhere on the board
COL5: U5.36 (GPIO24); also elsewhere on the board
COL6: U5.37 (GPIO25); also elsewhere on the board
COL7: U5.38 (GPIO26_ADC0); also elsewhere on the board
COL8: U5.39 (GPIO27_ADC1); also elsewhere on the board
COL9: U5.6 (GPIO4); also elsewhere on the board
COL10: U5.7 (GPIO5); also elsewhere on the board
COL11: U5.27 (GPIO16); also elsewhere on the board
COL12: U5.28 (GPIO17); also elsewhere on the board
COL13: U5.12 (GPIO9); also elsewhere on the board
COL14: U5.13 (GPIO10); also elsewhere on the board
D+: R10.2, U2.1 (I/O1)
D-: R11.2, U2.3 (I/O2)
GND: C70.2, C80.2, C81.2, C82.2, C83.2, C84.2, C85.2, C86.2, C87.2, C88.2, C89.2, C90.2, C91.2, C92.2, C93.2, C94.2, C95.2, C96.2, C97.2, J2.A1 (GND), J2.A12 (GND), J2.B1 (GND), J2.B12 (GND), J2.S1 (SHIELD), J5.4, R1.1, R2.1, SW65.2, U2.2 (GND), U4.1 (GND), U5.19 (TESTEN), U5.57 (GND), U6.4 (GND), Y2.2, Y2.4
unnamed: C81.1, R12.2, Y2.3
unnamed: J2.A5 (CC1), R2.2
unnamed: J2.B5 (CC2), R1.2
unnamed: R7.2, U5.26 (RUN)
unnamed: R11.1, U5.46 (USB_DM)
unnamed: R10.1, U5.47 (USB_DP)
unnamed: C80.1, U5.20 (XIN), Y2.1
unnamed: R12.1, U5.21 (XOUT)
ROW0: U5.41 (GPIO29_ADC3); also elsewhere on the board
ROW1: U5.40 (GPIO28_ADC2); also elsewhere on the board
ROW2: U5.29 (GPIO18); also elsewhere on the board
ROW3: U5.15 (GPIO12); also elsewhere on the board
ROW4: U5.14 (GPIO11); also elsewhere on the board
USB_D+: J2.A6 (D+), J2.B6 (D+), U2.6 (I/O1)
USB_D-: J2.A7 (D-), J2.B7 (D-), U2.4 (I/O2)
VBUS: F1.2, J2.A4 (VBUS), J2.A9 (VBUS), J2.B4 (VBUS), J2.B9 (VBUS), U2.5 (VBUS)

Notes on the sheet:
RP2040 IOVDD, USBCDD, ADCVDD
RP2040 VREG IN/OUT
CLOSE TO FLASH CHIP
RP2040 DVDD

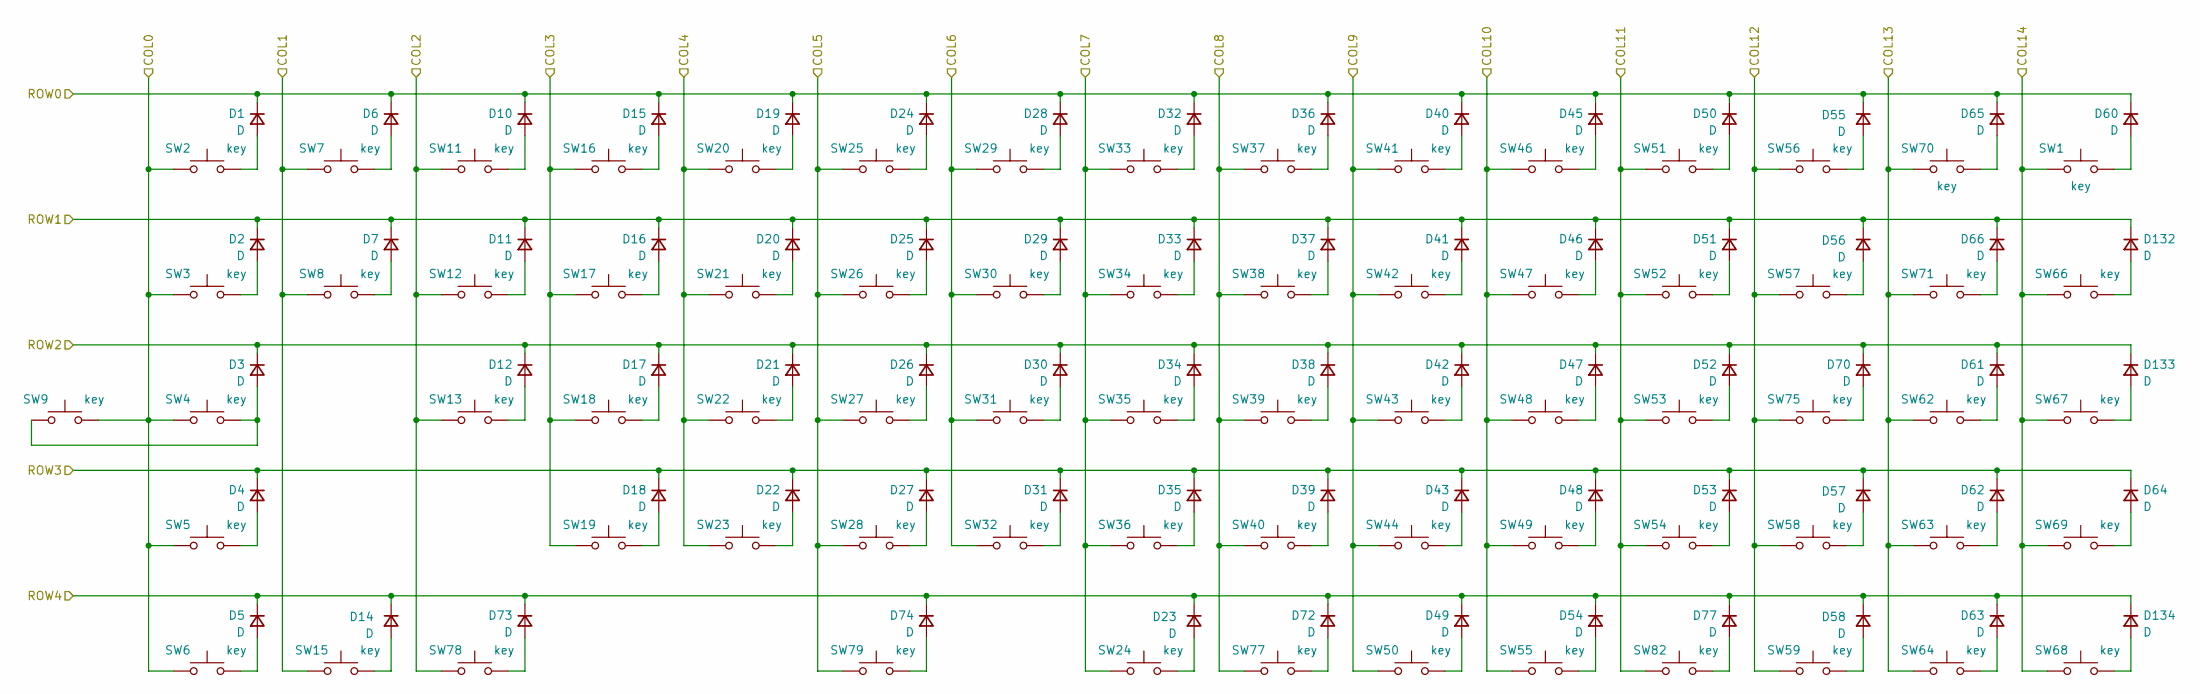
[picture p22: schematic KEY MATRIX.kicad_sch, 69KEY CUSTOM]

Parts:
D1, D2, D3, D4, D5, D6, D7, D10, D11, D12, D14, D15, D16, D17, D18, D19, D20, D21, D22, D23, D24, D25, D26, D27, D28, D29, D30, D31, D32, D33, D34, D35, D36, D37, D38, D39, D40, D41, D42, D43, D45, D46, D47, D48, D49, D50, D51, D52, D53, D54, D55, D56, D57, D58, D60, D61, D62, D63, D64, D65, D66, D70, D72, D73, D74, D77, D132, D133, D134: D; SOD-123
SW1, SW2, SW3, SW4, SW5, SW6, SW7, SW8, SW9, SW11, SW12, SW13, SW15, SW16, SW17, SW18, SW19, SW20, SW21, SW22, SW23, SW24, SW25, SW26, SW27, SW28, SW29, SW30, SW31, SW32, SW33, SW34, SW35, SW36, SW37, SW38, SW39, SW40, SW41, SW42, SW43, SW44, SW46, SW47, SW48, SW49, SW50, SW51, SW52, SW53, SW54, SW55, SW56, SW57, SW58, SW59, SW62, SW63, SW64, SW66, SW67, SW68, SW69, SW70, SW71, SW75, SW77, SW78, SW79, SW82: key; SW_Cherry_MX_1.00u_PCB

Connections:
COL0: SW2.1, SW3.1, SW4.1, SW5.1, SW6.1, SW9.2; also elsewhere on the board
COL1: SW7.1, SW8.1, SW15.1; also elsewhere on the board
COL2: SW11.1, SW12.1, SW13.1, SW78.1; also elsewhere on the board
COL3: SW16.1, SW17.1, SW18.1, SW19.1; also elsewhere on the board
COL4: SW20.1, SW21.1, SW22.1, SW23.1; also elsewhere on the board
COL5: SW25.1, SW26.1, SW27.1, SW28.1, SW79.1; also elsewhere on the board
COL6: SW29.1, SW30.1, SW31.1, SW32.1; also elsewhere on the board
COL7: SW24.1, SW33.1, SW34.1, SW35.1, SW36.1; also elsewhere on the board
COL8: SW37.1, SW38.1, SW39.1, SW40.1, SW77.1; also elsewhere on the board
COL9: SW41.1, SW42.1, SW43.1, SW44.1, SW50.1; also elsewhere on the board
COL10: SW46.1, SW47.1, SW48.1, SW49.1, SW55.1; also elsewhere on the board
COL11: SW51.1, SW52.1, SW53.1, SW54.1, SW82.1; also elsewhere on the board
COL12: SW56.1, SW57.1, SW58.1, SW59.1, SW75.1; also elsewhere on the board
COL13: SW62.1, SW63.1, SW64.1, SW70.1, SW71.1; also elsewhere on the board
COL14: SW1.1, SW66.1, SW67.1, SW68.1, SW69.1; also elsewhere on the board
unnamed: D1.2 (A), SW2.2
unnamed: D2.2 (A), SW3.2
unnamed: D3.2 (A), SW4.2, SW9.1
unnamed: D4.2 (A), SW5.2
unnamed: D5.2 (A), SW6.2
unnamed: D6.2 (A), SW7.2
unnamed: D7.2 (A), SW8.2
unnamed: D10.2 (A), SW11.2
unnamed: D11.2 (A), SW12.2
unnamed: D12.2 (A), SW13.2
unnamed: D14.2 (A), SW15.2
unnamed: D15.2 (A), SW16.2
unnamed: D16.2 (A), SW17.2
unnamed: D17.2 (A), SW18.2
unnamed: D18.2 (A), SW19.2
unnamed: D19.2 (A), SW20.2
unnamed: D20.2 (A), SW21.2
unnamed: D21.2 (A), SW22.2
unnamed: D22.2 (A), SW23.2
unnamed: D23.2 (A), SW24.2
unnamed: D24.2 (A), SW25.2
unnamed: D25.2 (A), SW26.2
unnamed: D26.2 (A), SW27.2
unnamed: D27.2 (A), SW28.2
unnamed: D28.2 (A), SW29.2
unnamed: D29.2 (A), SW30.2
unnamed: D30.2 (A), SW31.2
unnamed: D31.2 (A), SW32.2
unnamed: D32.2 (A), SW33.2
unnamed: D33.2 (A), SW34.2
unnamed: D34.2 (A), SW35.2
unnamed: D35.2 (A), SW36.2
unnamed: D36.2 (A), SW37.2
unnamed: D37.2 (A), SW38.2
unnamed: D38.2 (A), SW39.2
unnamed: D39.2 (A), SW40.2
unnamed: D40.2 (A), SW41.2
unnamed: D41.2 (A), SW42.2
unnamed: D42.2 (A), SW43.2
unnamed: D43.2 (A), SW44.2
unnamed: D45.2 (A), SW46.2
unnamed: D46.2 (A), SW47.2
unnamed: D47.2 (A), SW48.2
unnamed: D48.2 (A), SW49.2
unnamed: D49.2 (A), SW50.2
unnamed: D50.2 (A), SW51.2
unnamed: D51.2 (A), SW52.2
unnamed: D52.2 (A), SW53.2
unnamed: D53.2 (A), SW54.2
unnamed: D54.2 (A), SW55.2
unnamed: D55.2 (A), SW56.2
unnamed: D56.2 (A), SW57.2
unnamed: D57.2 (A), SW58.2
unnamed: D58.2 (A), SW59.2
unnamed: D60.2 (A), SW1.2
unnamed: D61.2 (A), SW62.2
unnamed: D62.2 (A), SW63.2
unnamed: D63.2 (A), SW64.2
unnamed: D64.2 (A), SW69.2
unnamed: D65.2 (A), SW70.2
unnamed: D66.2 (A), SW71.2
unnamed: D70.2 (A), SW75.2
unnamed: D72.2 (A), SW77.2
unnamed: D73.2 (A), SW78.2
unnamed: D74.2 (A), SW79.2
unnamed: D77.2 (A), SW82.2
unnamed: D132.2 (A), SW66.2
unnamed: D133.2 (A), SW67.2
unnamed: D134.2 (A), SW68.2
ROW0: D1.1 (K), D6.1 (K), D10.1 (K), D15.1 (K), D19.1 (K), D24.1 (K), D28.1 (K), D32.1 (K), D36.1 (K), D40.1 (K), D45.1 (K), D50.1 (K), D55.1 (K), D60.1 (K), D65.1 (K); also elsewhere on the board
ROW1: D2.1 (K), D7.1 (K), D11.1 (K), D16.1 (K), D20.1 (K), D25.1 (K), D29.1 (K), D33.1 (K), D37.1 (K), D41.1 (K), D46.1 (K), D51.1 (K), D56.1 (K), D66.1 (K), D132.1 (K); also elsewhere on the board
ROW2: D3.1 (K), D12.1 (K), D17.1 (K), D21.1 (K), D26.1 (K), D30.1 (K), D34.1 (K), D38.1 (K), D42.1 (K), D47.1 (K), D52.1 (K), D61.1 (K), D70.1 (K), D133.1 (K); also elsewhere on the board
ROW3: D4.1 (K), D18.1 (K), D22.1 (K), D27.1 (K), D31.1 (K), D35.1 (K), D39.1 (K), D43.1 (K), D48.1 (K), D53.1 (K), D57.1 (K), D62.1 (K), D64.1 (K); also elsewhere on the board
ROW4: D5.1 (K), D14.1 (K), D23.1 (K), D49.1 (K), D54.1 (K), D58.1 (K), D63.1 (K), D72.1 (K), D73.1 (K), D74.1 (K), D77.1 (K), D134.1 (K); also elsewhere on the board

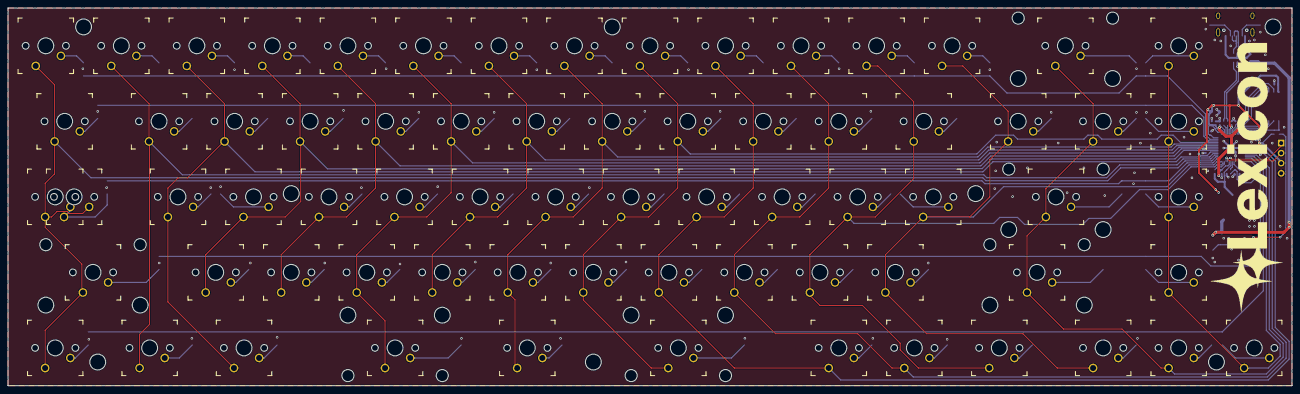
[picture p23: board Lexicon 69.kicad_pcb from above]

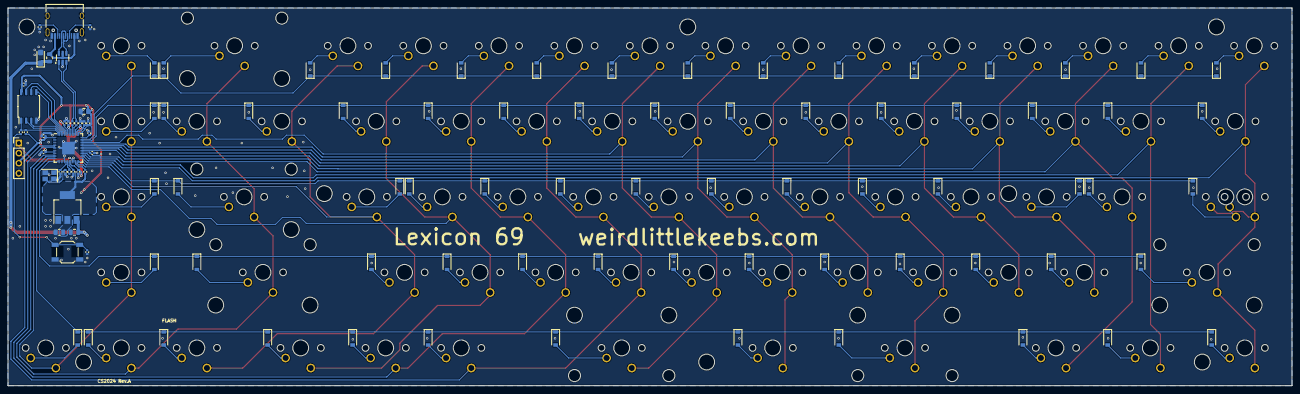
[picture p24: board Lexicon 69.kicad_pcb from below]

Board: 2 copper layers, 323.9 x 95.2 mm, 175 parts (105 on the bottom side), 115 nets.

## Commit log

2026-02-11 Add readme for Lexicon Case project
2026-02-11 Add image to case readme
    Added an image to the readme for visual reference.

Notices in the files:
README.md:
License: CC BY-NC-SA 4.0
